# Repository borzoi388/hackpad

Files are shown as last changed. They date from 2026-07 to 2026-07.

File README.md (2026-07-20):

# Fishpad
Fishpad is the 9-key fish-shaped macropad of my dreams with an OLED display and a rotary encoder. Uses QMK firmware and it will have VIA support C:

## Features:

whole thing
- 9 switches and a rotary encoder! (sadly no click on the encoder :c)
- 128x32 OLED screen
- LED underglow
- Case that's supposed to look like a fish?

## Case: 

Sandwich mount! Made in Onshape. The case has 3 parts, a bottom, plate for the keys, and a top. (all different colors in the picture :D). Also has a fun mouth-shaped usb cutout.

## PCB:

Schematic
schematic

PCB
pcb

Made with <3 in Kicad. Silkscreen imported from Figma. Time spent on the pcb was journaled 

## Firmware:

- Used QMK and used adafruit/macropad as a template since it had similar features to mine
- Not entirely finished, I will be using VIA to change the macros and leds
- I did add two layers of macros for now, one for gaming and one for drawing. Will probably change in the future!

# BOM:

    1x Seeed XIAO RP2040
    9x through-hole 1N4148 Diodes
    9x MX-Style switches
    1x EC11 Rotary encoders
    1x 0.91 inch OLED display
    9x white blank DSA keycaps
    9x SK6812 MINI-E LEDs
    4x M3x16mm screws
    1x Case (three 3d printed parts)

yup i copied this from hackpad website

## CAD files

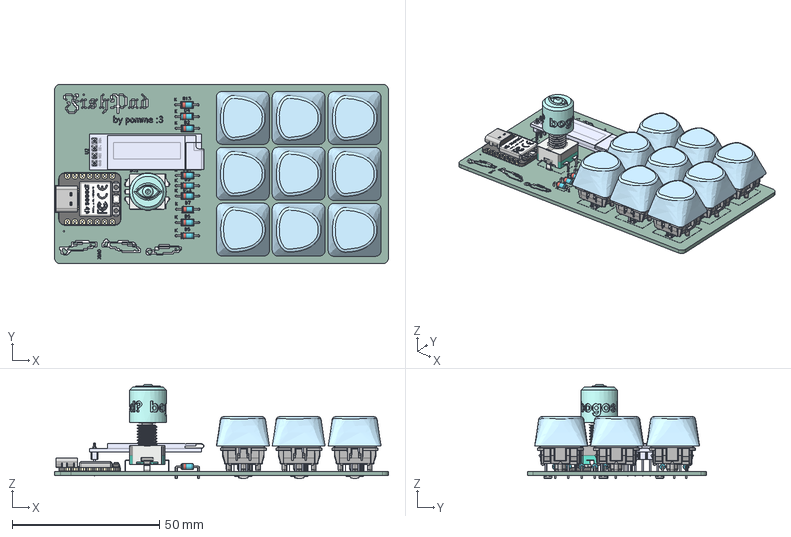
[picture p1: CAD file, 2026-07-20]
pcb/fishpad_pcb.step
113.6 x 61.0 x 32.1 mm
D_DO-35_SOD27_P7.62mm_Horizontal x 9
MX Öá °´¼ü¡ä_¨¹___¡§1 x 9
MX ס סͥ¨¢¨¬_¡§¡顧__ x 9
MXס ϞñLEDLEDLED x 9
MXÖá ÖáÌå µ×²¿ ¦Ì¡Á2__Ä¬ÈÏ_¨¢2____¨¨_ x 9
֫½ğ__Ĭɏ__¨¨_ x 9
type-c v2
smd_button v3
DOUT
DIN
VSS
VDD
smd_button v3(Mirror)
0.91in OLED
ѽת±ძǷ
Pin1 x 9
Pin2 x 9
Pin3 x 9
Pin4 x 9
hackpad2-unsaved-export-ECxtgQ_silkscreen x 2
hackpad2-unsaved-export-ECxtgQ_PCB

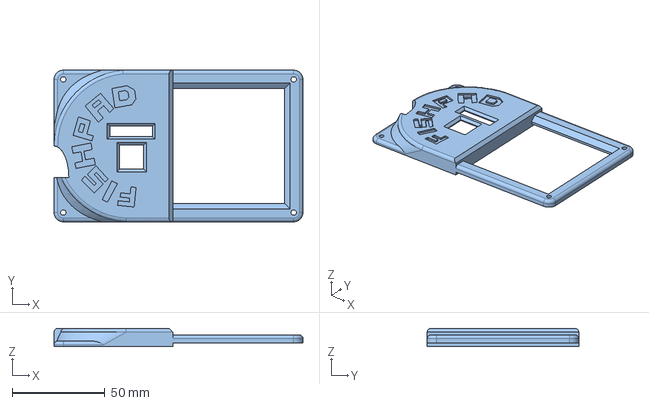
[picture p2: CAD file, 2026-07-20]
production/fishpad_top.step
134.3 x 81.8 x 9.83 mm

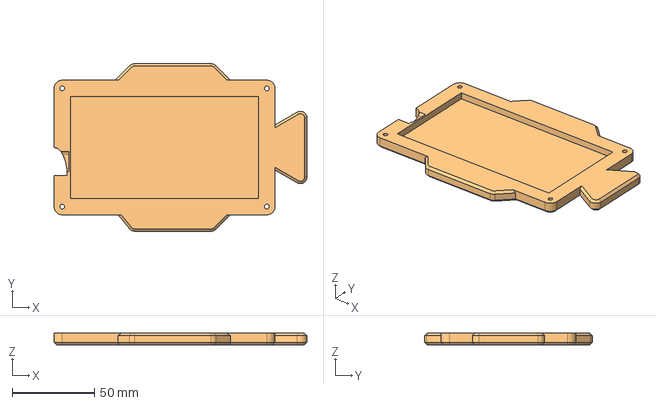
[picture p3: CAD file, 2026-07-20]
production/fishpad_bottom.step
153.7 x 101.8 x 7.10 mm

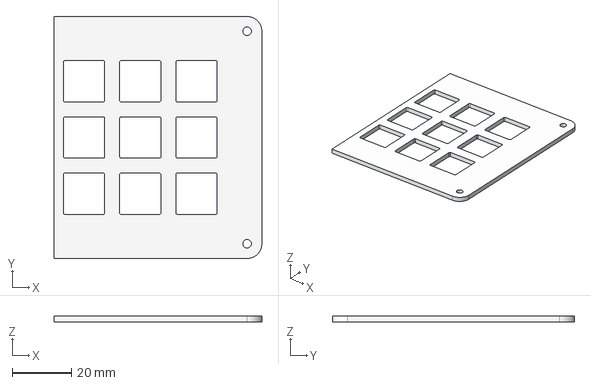
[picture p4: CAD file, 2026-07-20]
production/fishpad_plate.step
70.2 x 81.8 x 2.00 mm

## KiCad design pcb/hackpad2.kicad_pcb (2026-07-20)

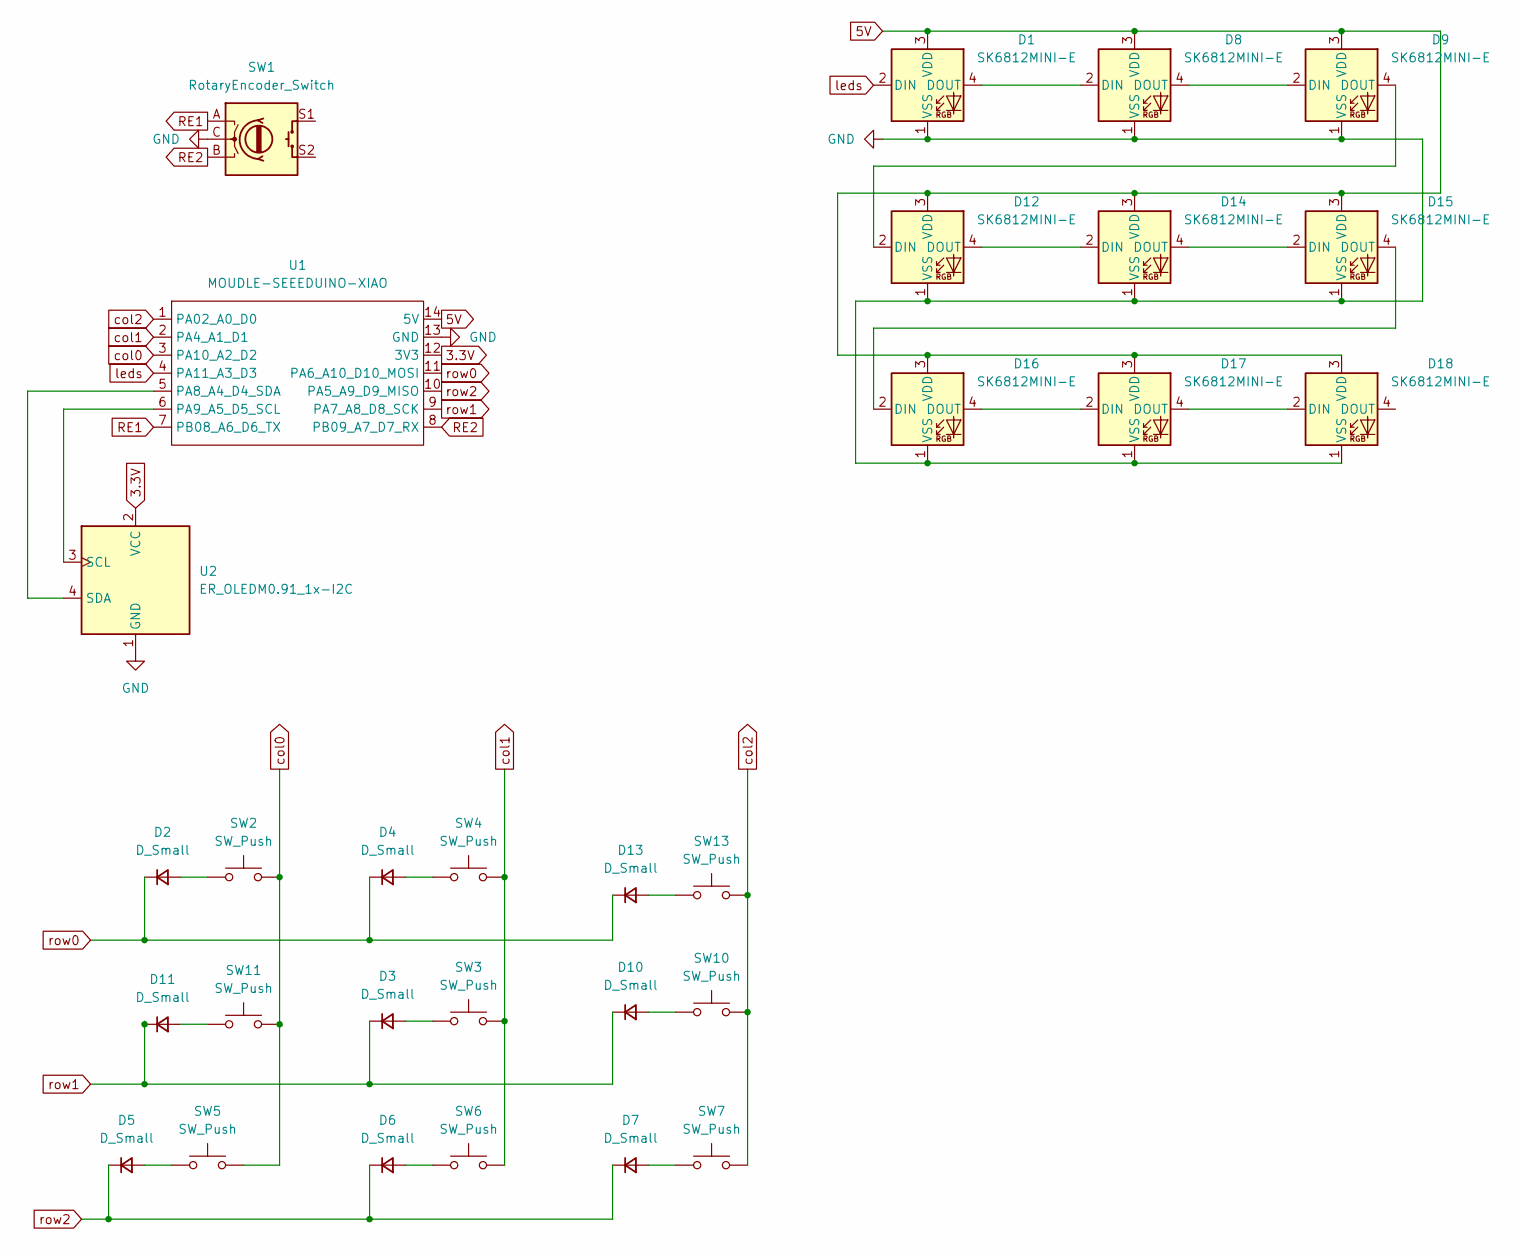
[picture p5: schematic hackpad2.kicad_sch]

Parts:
D1, D8, D9, D12, D14, D15, D16, D17, D18: SK6812MINI-E; LED_SK6812MINI-E_3.2x2.8mm_P1.5mm_ReverseMount
D2, D3, D4, D5, D6, D7, D10, D11, D13: D_Small; D_DO-35_SOD27_P7.62mm_Horizontal
SW1: RotaryEncoder_Switch; RotaryEncoder_Alps_EC11E-Switch_Vertical_H20mm
SW2, SW3, SW4, SW5, SW6, SW7, SW10, SW11, SW13: SW_Push; SW_Cherry_MX_1.00u_PCB
U1: MOUDLE-SEEEDUINO-XIAO; XIAO-Generic-Hybrid-14P-2.54-21X17.8MM
U2: ER_OLEDM0.91_1x-I2C

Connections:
3.3V: U1.12 (3V3), U2.2 (VCC)
5V: D1.3 (VDD), D8.3 (VDD), D9.3 (VDD), D12.3 (VDD), D14.3 (VDD), D15.3 (VDD), D16.3 (VDD), D17.3 (VDD), D18.3 (VDD), U1.14 (5V)
GND: D1.1 (VSS), D8.1 (VSS), D9.1 (VSS), D12.1 (VSS), D14.1 (VSS), D15.1 (VSS), D16.1 (VSS), D17.1 (VSS), D18.1 (VSS), SW1.C, U1.13 (GND), U2.1 (GND)
unnamed: D1.4 (DOUT), D8.2 (DIN)
unnamed: D2.2 (A), SW2.1
unnamed: D3.2 (A), SW3.1
unnamed: D4.2 (A), SW4.1
unnamed: D5.2 (A), SW5.1
unnamed: D6.2 (A), SW6.1
unnamed: D7.2 (A), SW7.1
unnamed: D8.4 (DOUT), D9.2 (DIN)
unnamed: D10.2 (A), SW10.1
unnamed: D11.2 (A), SW11.1
unnamed: D9.4 (DOUT), D12.2 (DIN)
unnamed: D12.4 (DOUT), D14.2 (DIN)
unnamed: D13.2 (A), SW13.1
unnamed: D14.4 (DOUT), D15.2 (DIN)
unnamed: D15.4 (DOUT), D16.2 (DIN)
unnamed: D16.4 (DOUT), D17.2 (DIN)
unnamed: D17.4 (DOUT), D18.2 (DIN)
unnamed: U1.5 (PA8_A4_D4_SDA), U2.4 (SDA)
unnamed: U1.6 (PA9_A5_D5_SCL), U2.3 (SCL)
RE1: SW1.A, U1.7 (PB08_A6_D6_TX)
RE2: SW1.B, U1.8 (PB09_A7_D7_RX)
col0: SW2.2, SW5.2, SW11.2, U1.3 (PA10_A2_D2)
col1: SW3.2, SW4.2, SW6.2, U1.2 (PA4_A1_D1)
col2: SW7.2, SW10.2, SW13.2, U1.1 (PA02_A0_D0)
leds: D1.2 (DIN), U1.4 (PA11_A3_D3)
row0: D2.1 (K), D4.1 (K), D13.1 (K), U1.11 (PA6_A10_D10_MOSI)
row1: D3.1 (K), D10.1 (K), D11.1 (K), U1.9 (PA7_A8_D8_SCK)
row2: D5.1 (K), D6.1 (K), D7.1 (K), U1.10 (PA5_A9_D9_MISO)

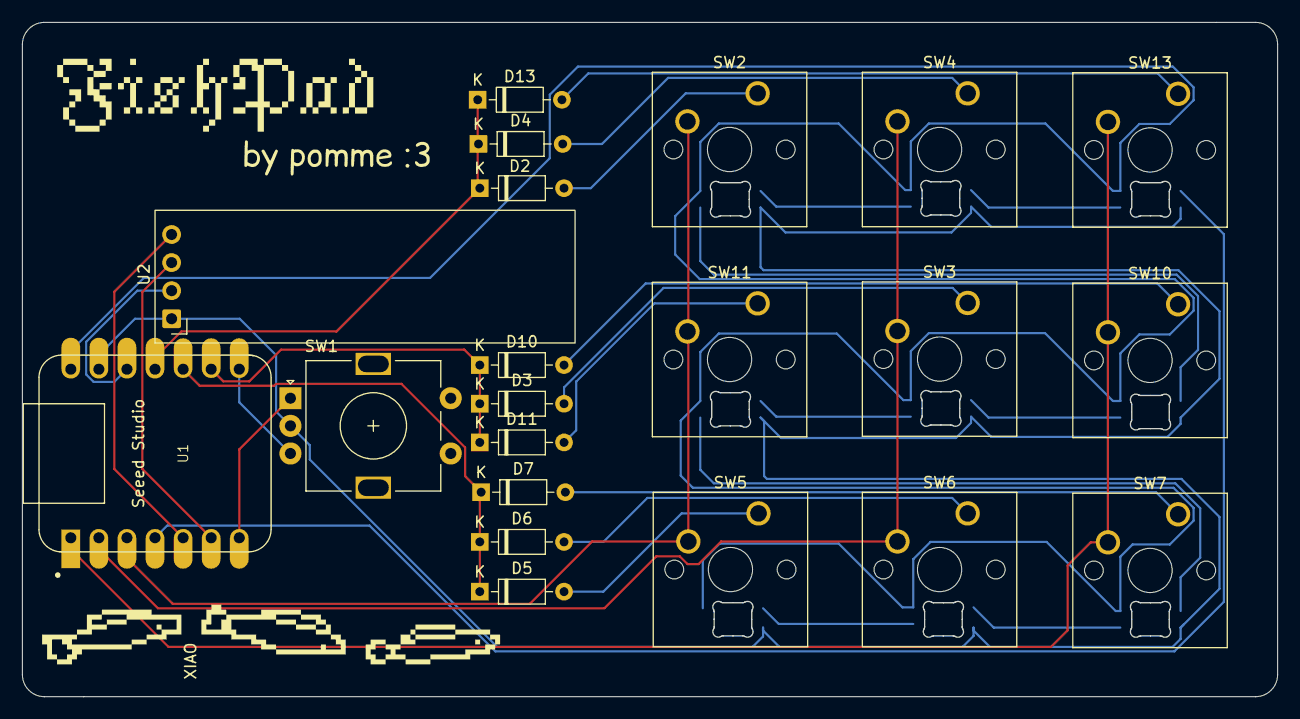
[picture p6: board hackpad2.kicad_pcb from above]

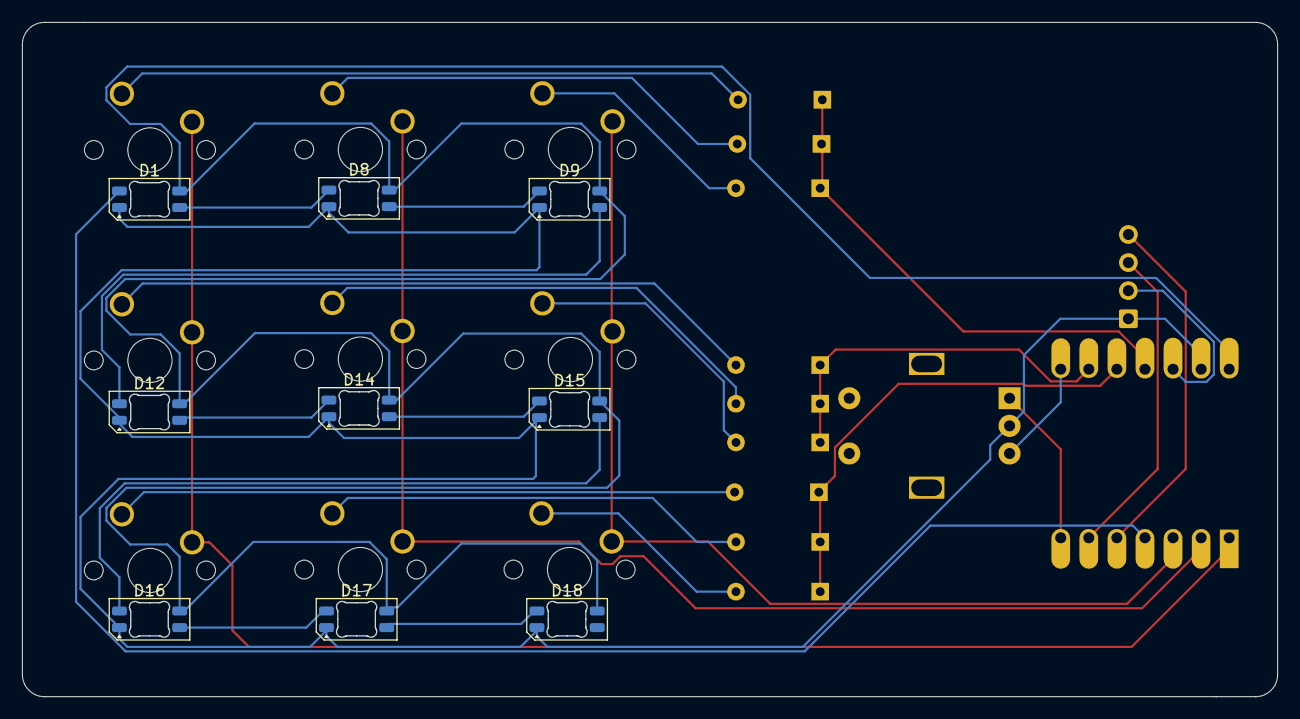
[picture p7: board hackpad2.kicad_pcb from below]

Board: 2 copper layers, 113.6 x 61.0 mm, 30 parts (9 on the bottom side), 31 nets.

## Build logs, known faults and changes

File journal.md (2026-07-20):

# 6/25 Working on the pcb schematic
Spent about 2 hours on this. 
schematic
(I did eventually fix the diodes that weren't connected to the wires)

First set up the repo and kicad project, finding some of the symbols and footprints I needed (OLED and rotary encoder, still need to get the LEDs'). In the process I learned that submodules were a thing and got the OLED display's footprint linked :,D 

On to the PCB schematic - I did the OLED display first (and spent way too long finding the correct symbol for it). I watched some of [this tutorial](https://www.youtube.com/watch?v=dW0GBJ2mwgY) to see how it's wired since the video used the same type of microcontroller. (does it matter if it's the same? idk)

After that, I was beginning to work on the keys, but thought it would probably be best to have an idea of where I wanted things to go first, so I settled on this design
sketch
I was originally going to have a 6x2 keypad since I wanted it to look long like a fish, but decided to make it 4x3 instead to conserve a switch. I also want to try adding a LED underglow, but we'll see how that goes.

I referenced ai03's pcb tutorial for the matrix wiring, but I think I got the gist of it from browsing other Hack Clubbers' finished macropads c:

Next, I need to learn how datasheets work cuz they are probably important :sob: as well as adding the LEDs and rotary encoders to the schematic.  

# 6/29 pcb schematic finished?

Spent about 30mins on this
schematic done

finished adding everything i wanted to the schematic (a rotary encoder and LEDs for the epic underglow)

Sadly, I ended up eliminating a column of the keyboard to give myself another pin on the microcontroller for the leds.

referenced the "idea for schematic" section of [this tutorial](https://www.youtube.com/watch?v=9j-y6XlaE80) to see how the rotary encoder was wired. I did a little reading on pull up resistors but didn't really get it, from what I understand it ensures that the switch has a defined level when there's no current? idk, anyway i found out later that the microcontroller has built in pull up resistors though so didn't have to deal with them.

The video told me to connect the shared contact between switches A and B to ground as well as one side of the push button to ground and everything else to VCC with the resistors, though I saw it done differently by the schematics I looked at from other finished hackpads (connecting everything but C to different pins on the microcontroller) so I ended up copying the other hackpads (apart from leaving one side of the push button to ground). I'm not sure if this still works, but if it doesn't, I might not use the push button because I'm thinking of using the encoder to switch colors on the underglow or something. Then I'll be able to add back the column on the keyboard :D

The leds were pretty straightforward. With the explanation on the hackpad website and looking at some of the other hackpad designs, I just wired them accordingly. 

# 6/29 part 2, working on routing

1.5 hours ish so far!

routing

I spent a while struggling on the layout first. I still want to do a fish shape but I fear it might be turning out a little cursed. I imagine the eye is the encoder and the oled is an eyebrow or something. The keys are the scales and you plug the usb into the mouth. Anyways, started trying to route it. It was harder than I thought- I had to clear everything a couple of times (as you can see in the picture, I just did that XD)

I just reorganized the diodes and keys a little so it should be a little easier to route. I put the keys that were previously in columns on the schematic into rows so that the routes shouldn't get in the way of each other if they're on the same layer and put the diodes in groups. I'll probably rename the rows to columns now so I don't get confused lilwhen it's firmware time :P

# 7/1, done routing maybe?
Time spent: uhh I don't know honestly maybe like 2 or 3 hours :sob:

routing2

I was just trying out different ways to route it heh- I reset it a couple of times. I did end up removing the press function on the encoder cuz I had to replace it with something I forgot to connect to the microcontroller :P
I'm pretty happy I was able to do almost everything on one layer (I was sure I'd have to ground and vcc on different ones) so yea :D
Not sure if I'll try rerouting it, kinda just want to move on to the CAD

# 7/1 part 2, lil bit of silkscreen art
Time spent: 45 min

silkscreen

decided to add some art to the margins, I named it fishpad and drew some little fish :D

# 7/5 fixing stuff

Time spent: ~1.5 hrs

model
pcb

I fixed the global labels pointing the wrong way in the schematic, also had to reroute it because I put the leds backwards - it was much quicker though since I knew how I wanted to route it. I also uploaded 3d models for each of the footprints and imported the 3d model of the whole pcb into an onshape document so I can model the case around it. Thx to people in #hackpad for correcting me on my pcb and kicad c:

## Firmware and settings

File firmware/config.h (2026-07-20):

/* Copyright 2022 Jose Pablo Ramirez <jp.ramangulo@gmail.com>
 *
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
 * You should have received a copy of the GNU General Public License
 * along with this program.  If not, see <http://www.gnu.org/licenses/>.
 */

#pragma once

/* OLED SPI Defines */
#define OLED_DISPLAY_128X64
#define OLED_IC OLED_IC_SH1106

/* OLED SPI Pins */
#define OLED_DC_PIN GP24
#define OLED_CS_PIN GP22
#define OLED_RST_PIN GP23

/* Shift OLED columns by 2 pixels */
#define OLED_COLUMN_OFFSET 2

/* Divisor for OLED */
#define OLED_SPI_DIVISOR 4

/* ChibiOS SPI definitions */
#define SPI_DRIVER SPID1
#define SPI_SCK_PIN GP26
#define SPI_MOSI_PIN GP27
#define SPI_MISO_PIN GP28

/* Double tap the side button to enter bootloader */
#define RP2040_BOOTLOADER_DOUBLE_TAP_RESET
#define RP2040_BOOTLOADER_DOUBLE_TAP_RESET_LED GP13
#define RP2040_BOOTLOADER_DOUBLE_TAP_RESET_TIMEOUT 500U

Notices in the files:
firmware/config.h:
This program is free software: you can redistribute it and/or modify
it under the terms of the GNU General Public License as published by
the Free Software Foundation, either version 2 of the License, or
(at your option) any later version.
